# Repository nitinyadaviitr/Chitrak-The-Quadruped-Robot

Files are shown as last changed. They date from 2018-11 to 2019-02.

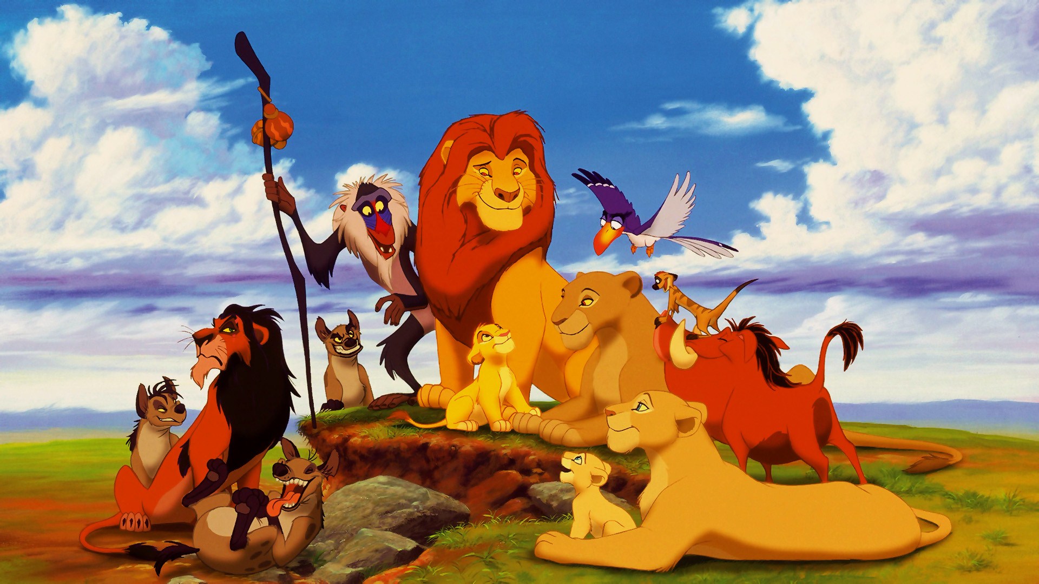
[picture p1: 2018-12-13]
PPT/The-Lion-King-complete-guide-to-the-lion-king-30912711-1920-1080.jpg

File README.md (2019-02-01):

MaRS_Kitty
Walking Quadruped Robot Kitty is a Quadruped that we are building under Models and Robotics Section, IIT Roorkee. 
This four legged walking robot will mimic the gait cycle of a cat with a soul purpose of providing help in natural calamities where 
normal robots find it difficult to move. 
Thank You.

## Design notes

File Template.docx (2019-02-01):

# KITTY ROBOT

Models and Robotics Section, Student Technical Council, IIT Roorkee

Replace this image. | Replace this image.

## About

Introduction

Less than half the Earth's landmass is accessible to existing wheeled and tracked vehicles. Our mission is to develop a rough-terrain robot that captures the mobility, autonomy, and speed of living creatures. Kitty will travel in outdoor terrain that is too steep, rutted, rocky, wet, muddy, and snowy land which clutter limit the utility of wheeled vehicles. Kitty Robot is aimed to be a dynamically stable quadruped robot with sophisticated computing, and power systems, advanced actuators and dynamic controls. For Short missions, the whole gear weighs nearly 58 Kg.

Weight decreases the amount of food and ammunition that can be carried in a single deployment, so supplies are to be provided to them again. Providing Backup Supplies and Care packages to soldiers increases the risk of life for Backup team. Kitty uses 4Lipo batteries(1 for each leg) which drives 8 Worm-Gear motors. Each leg has 2DOF. Each actuator unit consists of a rotary encoder attached to it for the feedback of angular rotation of leg about a joint.

Our Proposal

Utilize the space here for preliminary information about the project, motivation, execution, composition etc.

Team Size: 8

Impact on Society:

Ongoing Work

Problems With Current Robotic Waiters

How are we different from others?

Team Composition

Nitin Yadav

Yawan Gupta

Harshil Kumar Patel

Ujjwal Baranwal

Divyansh Gupta

Prashant Kumar

Avdesh Ranwa

Yashutosh Bansal

Replace this image. | Replace this image.

## Impact

Include key achievements, publications awards etc.

Highlight key learnings developed through the project etc.

## Contact

Models and Robotics Section

IIT Roorkee

Mail ID: nyadav@ee.iitr.ac.in

Website: mars.iitr.ac.in

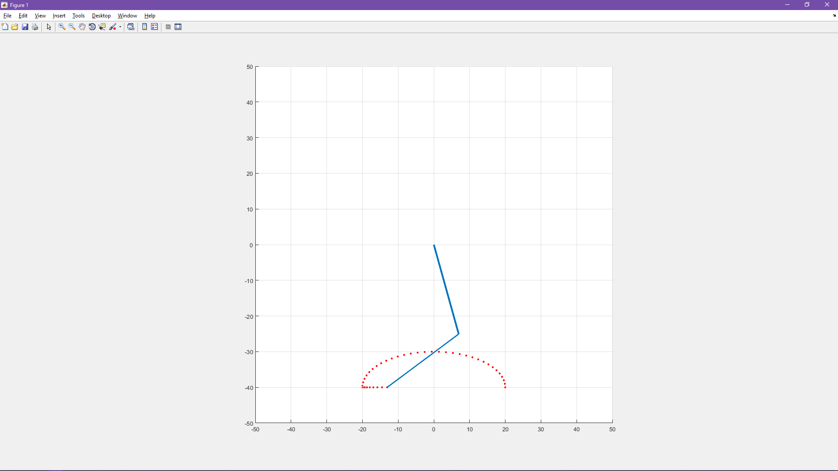
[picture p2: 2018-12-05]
PPT/Pics/Screenshot (137).png

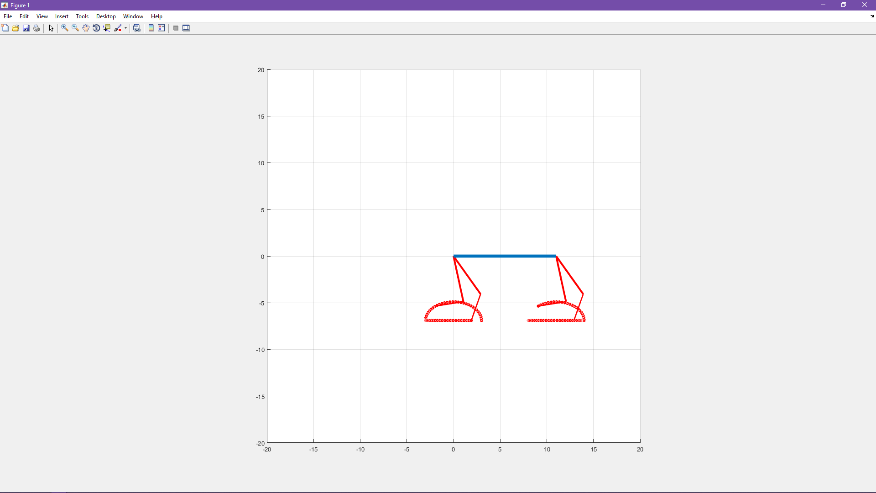
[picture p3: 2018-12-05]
PPT/Pics/Screenshot (147).png

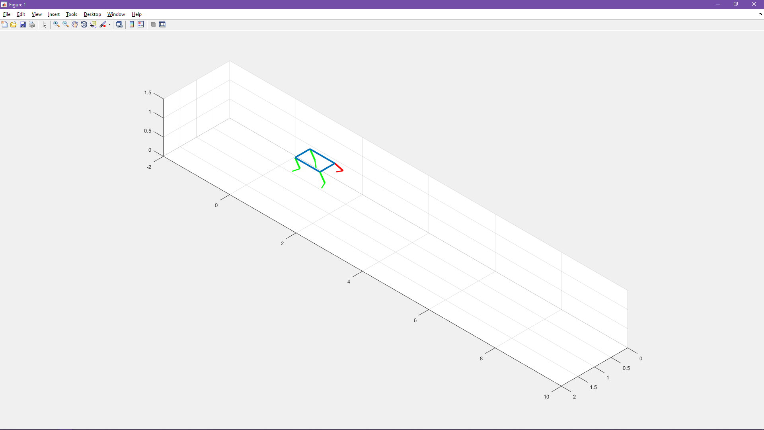
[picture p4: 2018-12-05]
PPT/Pics/Screenshot (134).png

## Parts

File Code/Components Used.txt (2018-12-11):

1. Cytron Motor Driver 4
2. LiPo Batteries 5
3. Rotary Encoders 8
4. Worm-Gear Motors 8
5. Arduino-Mega2560 2
6. MPU-9250 1

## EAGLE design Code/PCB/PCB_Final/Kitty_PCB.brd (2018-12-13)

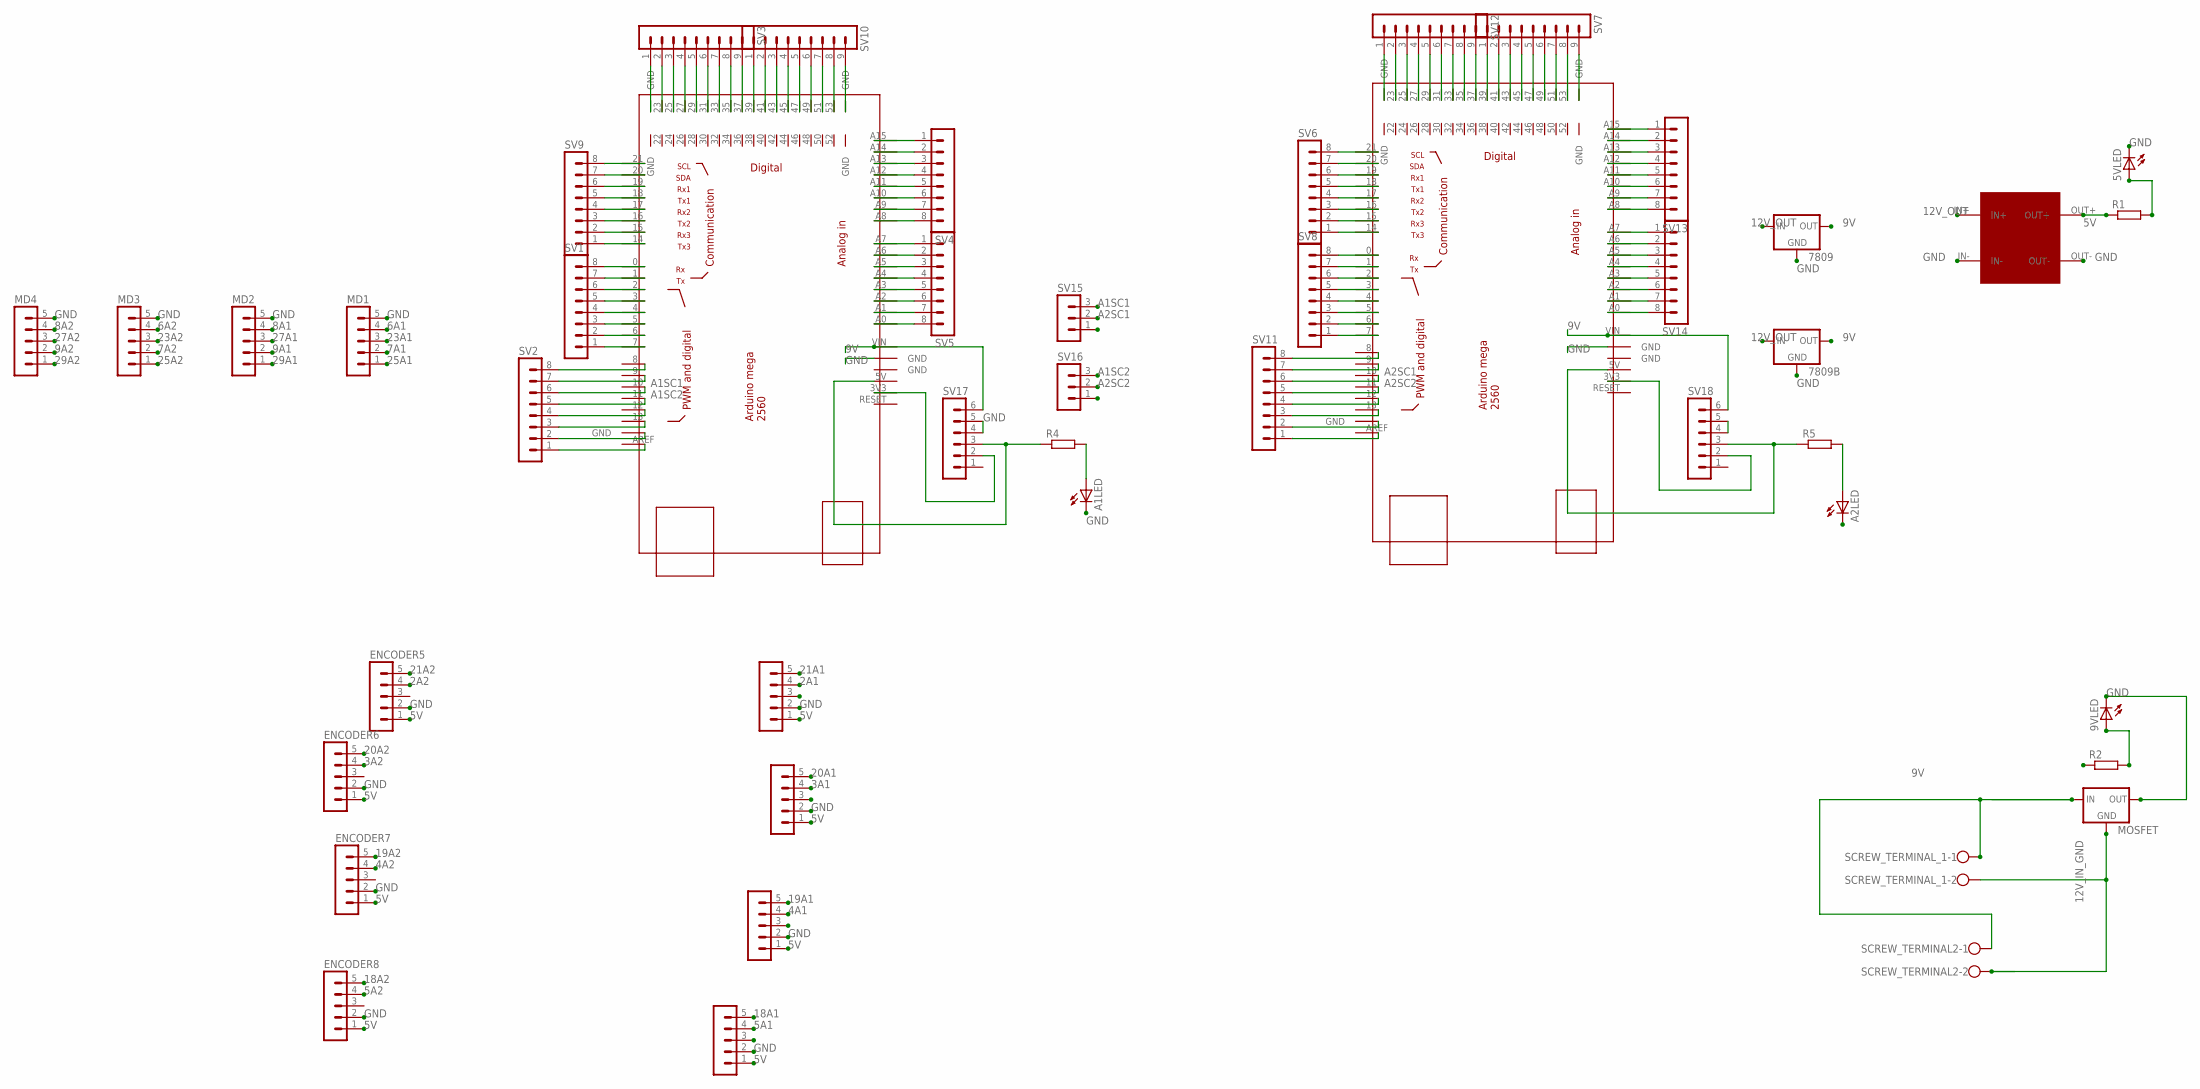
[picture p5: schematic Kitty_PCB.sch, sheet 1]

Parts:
5VLED, 9VLED: LED; LED3MM
7809, 7809B: VOLTAGE_REGULATOR_78XXS; 78XXS
A1LED, A2LED: LED; LED3MM
ARDUINO1, ARDUINO2: MEGA_DEVICE; MEGABOX
ENCODER1, ENCODER2, ENCODER3, ENCODER4, ENCODER5, ENCODER6, ENCODER7, ENCODER8: RELIMATE_05-1; MA05-1
MD1, MD2, MD3, MD4: RELIMATE_05-1; MA05-1
MOSFET: VOLTAGE_REGULATOR_78XXS; 78XXS
R1, R2, R4, R5: RESISTANCE0207/10; 0207/10
SCREW_TERMINAL2: SCREW_TERMINAL_POWER; POWER_CONNECTOR
SCREW_TERMINAL_1: SCREW_TERMINAL_POWER; POWER_CONNECTOR
SV1, SV2, SV4, SV5, SV6, SV8, SV9, SV11, SV13, SV14: RELIMATE_08-1; MA08-1
SV3, SV7, SV10, SV12: RELIMATE_09-1; MA09-1
SV15, SV16: RELIMATE_03-1; MA03-1
SV17, SV18: RELIMATE_06-1; MA06-1
U$1: BUCK_CONVERTER

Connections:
0A1: ARDUINO1.0, SV1.8
0A2: ARDUINO2.0, SV8.8
1A1: ARDUINO1.1, SV1.7
1A2: ARDUINO2.1, SV8.7
2A1: ARDUINO1.2, ENCODER1.4, SV1.6
2A2: ARDUINO2.2, ENCODER5.4, SV8.6
3A1: ARDUINO1.3, ENCODER2.4, SV1.5
3A2: ARDUINO2.3, ENCODER6.4, SV8.5
4A1: ARDUINO1.4, ENCODER3.4, SV1.4
4A2: ARDUINO2.4, ENCODER7.4, SV8.4
5A1: ARDUINO1.5, ENCODER4.4, SV1.3
5A2: ARDUINO2.5, ENCODER8.4, SV8.3
5V: ENCODER1.1, ENCODER2.1, ENCODER3.1, ENCODER4.1, ENCODER5.1, ENCODER6.1, ENCODER7.1, ENCODER8.1, R1.1, U$1.OUT+
6A1: ARDUINO1.6, MD1.4, SV1.2
6A2: ARDUINO2.6, MD3.4, SV8.2
7A1: ARDUINO1.7, MD1.2, SV1.1
7A2: ARDUINO2.7, MD3.2, SV8.1
8A1: ARDUINO1.8, MD2.4, SV2.8
8A2: ARDUINO2.8, MD4.4, SV11.8
9A1: MD2.2
9A2: ARDUINO1.9, ARDUINO2.9, MD4.2, SV2.7, SV11.7
9V: 7809.OUT, 7809B.OUT, ARDUINO1.VIN, ARDUINO2.VIN, R2.1, SV17.6, SV18.6
12A1: ARDUINO1.12, SV2.4
12A2: ARDUINO2.12, SV11.4
12V_IN_GND: MOSFET.GND, SCREW_TERMINAL2.2, SCREW_TERMINAL_1.2
12V_OUT: 7809.IN, 7809B.IN, MOSFET.IN, SCREW_TERMINAL2.1, SCREW_TERMINAL_1.1, U$1.IN+
13A1: ARDUINO1.13, SV2.3
13A2: ARDUINO2.13, SV11.3
14A1: ARDUINO1.14, SV9.1
14A2: ARDUINO2.14, SV6.1
15A1: ARDUINO1.15, SV9.2
15A2: ARDUINO2.15, SV6.2
16A1: ARDUINO1.16, SV9.3
16A2: ARDUINO2.16, SV6.3
17A1: ARDUINO1.17, SV9.4
17A2: ARDUINO2.17, SV6.4
18A1: ARDUINO1.18, ENCODER4.5, SV9.5
18A2: ARDUINO2.18, ENCODER8.5, SV6.5
19A1: ARDUINO1.19, ENCODER3.5, SV9.6
19A2: ARDUINO2.19, ENCODER7.5, SV6.6
20A1: ARDUINO1.20, ENCODER2.5, SV9.7
20A2: ARDUINO2.20, ENCODER6.5, SV6.7
21A1: ARDUINO1.21, ENCODER1.5, SV9.8
21A2: ARDUINO2.21, ENCODER5.5, SV6.8
23A1: ARDUINO1.23, MD1.3, SV3.2
23A2: ARDUINO2.23, MD3.3, SV12.2
25A1: ARDUINO1.25, MD1.1, SV3.3
25A2: ARDUINO2.25, MD3.1, SV12.3
27A1: ARDUINO1.27, MD2.3, SV3.4
27A2: ARDUINO2.27, MD4.3, SV12.4
29A1: ARDUINO1.29, MD2.1, SV3.5
29A2: ARDUINO2.29, MD4.1, SV12.5
31A1: ARDUINO1.31, SV3.6
31A2: ARDUINO2.31, SV12.6
33A1: ARDUINO1.33, SV3.7
33A2: ARDUINO2.33, SV12.7
35A1: ARDUINO1.35, SV3.8
35A2: ARDUINO2.35, SV12.8
37A1: ARDUINO1.37, SV3.9
37A2: ARDUINO2.37, SV12.9
A1SC1: ARDUINO1.10, SV2.6, SV15.3
A1SC2: ARDUINO1.11, SV2.5, SV16.3
A2SC1: ARDUINO2.10, SV11.6, SV15.2
A2SC2: ARDUINO2.11, SV11.5, SV16.2
GND: 5VLED.K (C), 9VLED.K (C), 7809.GND, 7809B.GND, A1LED.K (C), A2LED.K (C), ARDUINO1.GND@3 (GND), ARDUINO2.GND@3 (GND), ENCODER1.2, ENCODER2.2, ENCODER3.2, ENCODER4.2, ENCODER5.2, ENCODER6.2, ENCODER7.2, ENCODER8.2, MD1.5, MD2.5, MD3.5, MD4.5, MOSFET.OUT, SV17.4, SV17.5, U$1.IN-, U$1.OUT-
unnamed: ARDUINO1.3V3, SV17.2
unnamed: ARDUINO1.5V, R4.1, SV17.3
unnamed: 5VLED.A, R1.2
unnamed: SV18.4, SV18.5
unnamed: ARDUINO2.3V3, SV18.2
unnamed: ARDUINO2.5V, R5.1, SV18.3
unnamed: A1LED.A, R4.2
unnamed: A2LED.A, R5.2
unnamed: 9VLED.A, R2.2
unnamed: ARDUINO1.GND@5 (GND), SV3.1
unnamed: ARDUINO1.GND@1 (GND), SV2.2
unnamed: ARDUINO1.AREF, SV2.1
unnamed: ARDUINO1.A15, SV4.1
unnamed: ARDUINO1.A14, SV4.2
unnamed: ARDUINO1.A13, SV4.3
unnamed: ARDUINO1.A12, SV4.4
unnamed: ARDUINO1.A11, SV4.5
unnamed: ARDUINO1.A10, SV4.6
unnamed: ARDUINO1.A9, SV4.7
unnamed: ARDUINO1.A8, SV4.8
unnamed: ARDUINO1.A7, SV5.1
unnamed: ARDUINO1.A6, SV5.2
unnamed: ARDUINO1.A5, SV5.3
unnamed: ARDUINO1.A4, SV5.4
unnamed: ARDUINO1.A3, SV5.5
unnamed: ARDUINO1.A2, SV5.6
unnamed: ARDUINO1.A1, SV5.7
unnamed: ARDUINO1.A0, SV5.8
unnamed: ARDUINO2.GND@1 (GND), SV11.2
unnamed: ARDUINO2.AREF, SV11.1
unnamed: ARDUINO2.A15, SV13.1
unnamed: ARDUINO2.A14, SV13.2
unnamed: ARDUINO2.A13, SV13.3
unnamed: ARDUINO2.A12, SV13.4
unnamed: ARDUINO2.A11, SV13.5
unnamed: ARDUINO2.A10, SV13.6
unnamed: ARDUINO2.A9, SV13.7
unnamed: ARDUINO2.A8, SV13.8
unnamed: ARDUINO2.A7, SV14.1
unnamed: ARDUINO2.A6, SV14.2
unnamed: ARDUINO2.A5, SV14.3
unnamed: ARDUINO2.A4, SV14.4
unnamed: ARDUINO2.A3, SV14.5
unnamed: ARDUINO2.A2, SV14.6
unnamed: ARDUINO2.A1, SV14.7
unnamed: ARDUINO2.A0, SV14.8
unnamed: ARDUINO1.39, SV10.1
unnamed: ARDUINO1.41, SV10.2
unnamed: ARDUINO1.43, SV10.3
unnamed: ARDUINO1.45, SV10.4
unnamed: ARDUINO1.47, SV10.5
unnamed: ARDUINO1.49, SV10.6
unnamed: ARDUINO1.51, SV10.7
unnamed: ARDUINO1.53, SV10.8
unnamed: ARDUINO1.GND@7 (GND), SV10.9
unnamed: ARDUINO2.GND@5 (GND), SV12.1
unnamed: ARDUINO2.39, SV7.1
unnamed: ARDUINO2.41, SV7.2
unnamed: ARDUINO2.43, SV7.3
unnamed: ARDUINO2.45, SV7.4
unnamed: ARDUINO2.47, SV7.5
unnamed: ARDUINO2.49, SV7.6
unnamed: ARDUINO2.51, SV7.7
unnamed: ARDUINO2.53, SV7.8
unnamed: ARDUINO2.GND@7 (GND), SV7.9

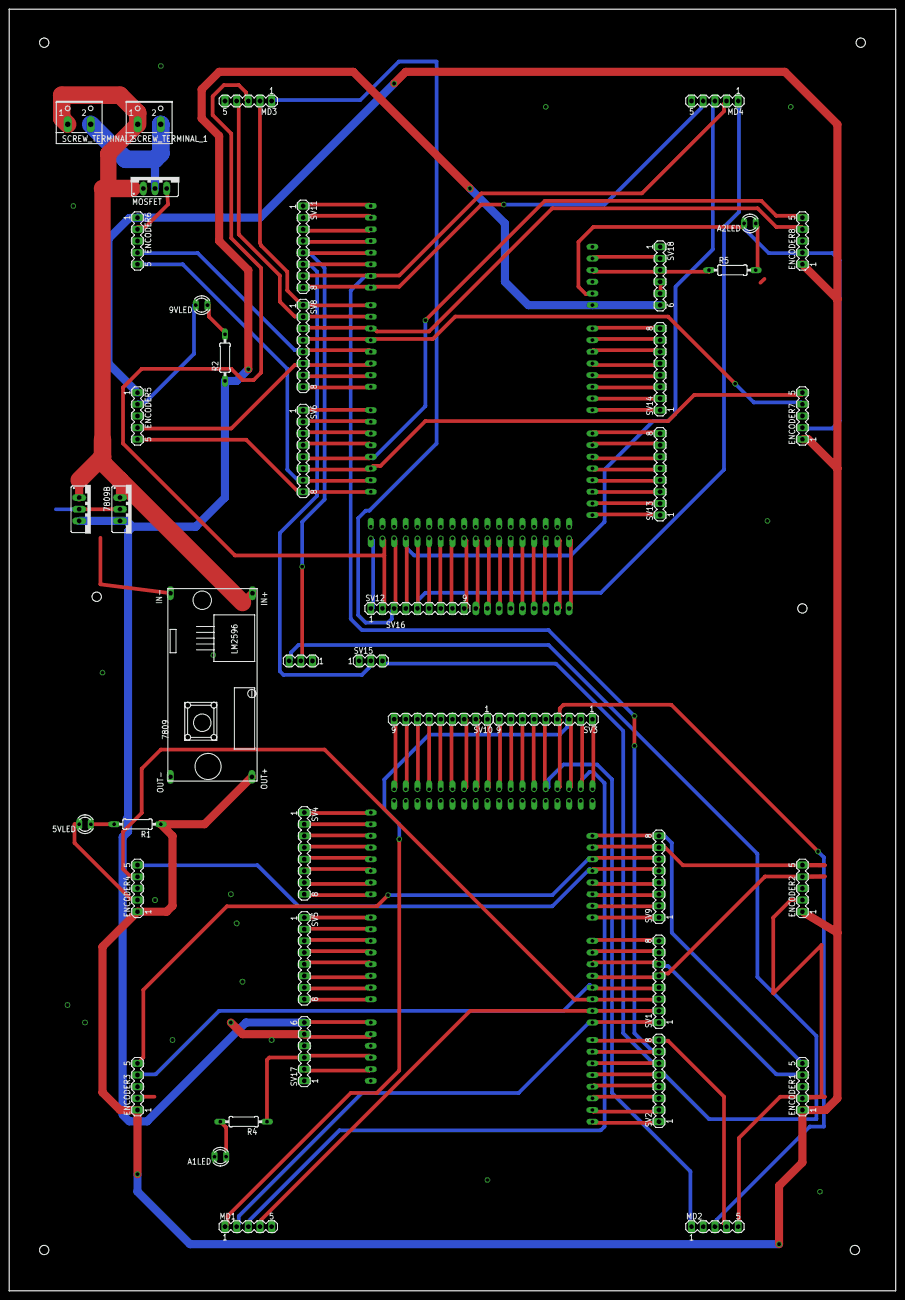
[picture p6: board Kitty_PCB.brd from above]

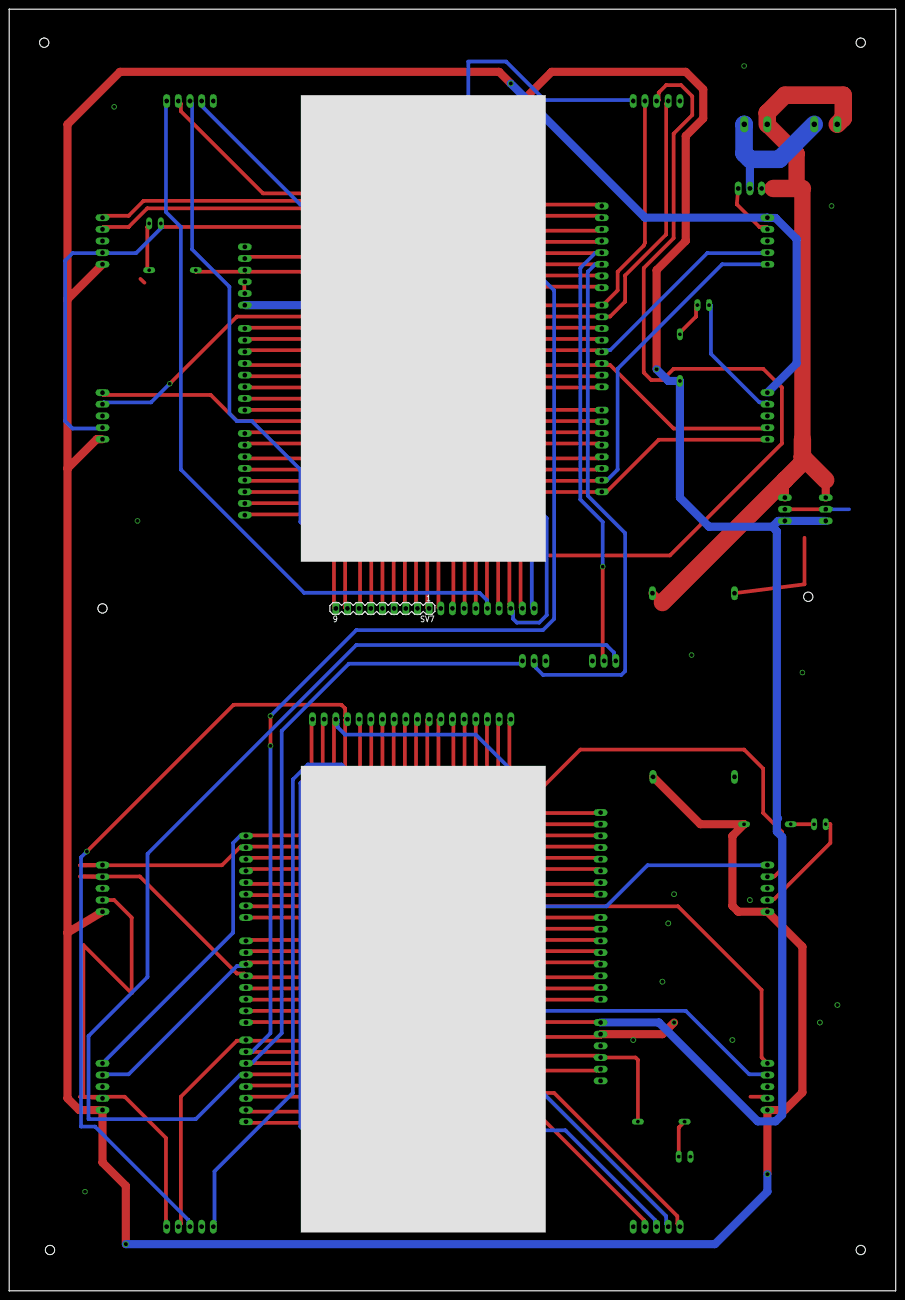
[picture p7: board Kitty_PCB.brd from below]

Board: 2 copper layers, 193.0 x 279.1 mm, 46 parts (3 on the bottom side), 129 nets.

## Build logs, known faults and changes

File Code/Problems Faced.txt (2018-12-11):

1. We are using 2 Arduino-Mega2560 so we need to use 1 attach_interrupt() pins instead of two for each encoder as Arduino Mega has 6 attach interrupts so we need atleast 2 Arduino to use 8 encoders.
2. In arduino mega, when we were using Tx-Rx pins(14-19) for writing analog value and direction into the motor driver, code was uploading but on giving the command to move the leg, no movement was observed. So we used digital pins(22-)for direction and only the PWM pins for writing the analog value, it worked properly.
3. For attach interrupt, we were using digitaltointerrupt() command for using interrupts and it did not work in mega but worked in uno. So we inserted manually the iterrupt pin number in Arduino-Mega from arduino website and it started working.
4. Encoder PPM value will be different to calculate angle when you are using one interrupt pin instead of two.
5. For applying Spline, the inverse Jacobian equation was to complex to be written in Arduino IDE, so we used a library for calculating inverse Matrix and perform other Matrix operations.
6. Timing Belt that was being used to hold the knee joint, was breaking very often. So we are searching for other alternatives.

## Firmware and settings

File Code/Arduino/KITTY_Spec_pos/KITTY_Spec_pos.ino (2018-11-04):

//Here 1 is for hip joint and 2 is for knee joint//
#define motor1  6
#define motor2  4
#define motor1pwm  10
#define motor2pwm  11

//Varaibles
float w=0.1, alpha, theta1c = 0.0 , theta2c = 0.0, theta1, theta2, error1, error2, correction1, correction2;
float dif_error1 , prev_error1 = 0.0 , dif_error2 , prev_error2 = 0.0 , I=0.0, l = 48.0;
float Kp1 = 0.75, Kp2 = 0.0, Kd1 = 0.3, Kd2 = 0.0 , Ki1 = 0.0;
int l1 = 26, l2 = 22, a = 20, b = 7;

//Encoder variables
volatile int temp1 , counter1 = 0;
volatile int temp2 , counter2 = 0;

void setup() {
  Serial.begin(9600);

  //Pins for encoders
  pinMode(2, INPUT_PULLUP);
  pinMode(3, INPUT_PULLUP);
  attachInterrupt(0, ai0, RISING);
  attachInterrupt(1, ai1, RISING);
  pinMode(20, INPUT_PULLUP);
  pinMode(21, INPUT_PULLUP);
  attachInterrupt(2, ai2, RISING);
  attachInterrupt(3, ai3, RISING);

  //Pins for Motors
  pinMode(motor1, OUTPUT);
  pinMode(motor1pwm, OUTPUT);
  pinMode(motor2, OUTPUT);
  pinMode(motor2pwm, OUTPUT);

  //Initial Conditions
//  digitalWrite(motor1, HIGH);
  
}
int flag =0;
void loop() {
if (flag == 1)
{ analogWrite(motor1pwm,0);
  Serial.println("stopped");
  }
  
 if (flag == 0){ 
  for (float t = 0; t <= 1000; t=t+0.3) {

    
//Ellipse coordinate update
//      float t = millis();
//      Serial.println(t);
//      float xe = a * cos(w*(t));
//      float ye = b * sin(w*(t)) - 40;
//      if (ye < -40) {
//    float  ye = -40;
//      }
    float xe = 48*cos(-35-w*(t) );
    float ye = 48*sin(-35-w*(t));

//Convert Encoder Output into angle
      if ( counter1 != temp1 ) {
        temp1 = counter1;
        if (counter1 > 1200) {
          counter1 = 0;
         }
        theta1c = - (counter1 * 0.3);
//        Serial.println (theta1c);
     }
      if ( counter2 != temp2 ) {
        temp2 = counter2;
        if (counter2 > 1200) {
          counter2 = 0;
        }
        theta2c = (counter2 * 0.3);
//        Serial.println (theta2c);
      }
//      

       

////Ellipse coordinates corresponding angle
      if (atan(ye / xe) > 0) {
        alpha = atan(ye / xe) - PI;
      }
      else {
        alpha = atan(ye / xe);
      }
      theta1 = 57.2958*(cosine_rule(l2, l1, sqrt((xe * xe) + (ye * ye))) + alpha);
      theta2 = 57.2958*(-PI + cosine_rule(sqrt(xe * xe + ye * ye), l1, l2));
      error1 = theta1 - theta1c;
      error2 = theta2 - theta2c;
      dif_error1 = error1 - prev_error1;
      prev_error1 = error1;
      dif_error2 = error2 - prev_error2;
      prev_error2 = error2;
      
      I += error1;
      correction1 = Kp1*error1 + Kd1*(dif_error1);//+ Ki1*(I);
      correction2 = Kp2*error2 + Kd2*(dif_error2);
//      Serial.println(error1);
//      correction1 = Kp1*error1;
//      correction2 = Kp2*error2;
      Serial.println(correction1);
//      Moving condtions
      if(theta1c < -30.0){
        flag = 1;
        break;
        }
      if(error1<0 ){
        upr_mtr_fwd();
        analogWrite(motor1pwm,abs(correction1));
        }
       else if(error1>0){
        upr_mtr_bwd();
        analogWrite(motor1pwm,abs(correction1));
        }

//      if(error2<0){
//        lwr_mtr_fwd();
//        analogWrite(motor2pwm,abs(correction2));
//        }
//      else if(error2>0){
//        lwr_mtr_bwd();
//        analogWrite(motor2pwm,abs(correction2));
//        }
//
////   float t0 = millis();
////   Serial.println(t0-t);
  }
 }
}

//Cosine Rule
float cosine_rule(float c, float b, float a) {
  float x = ( a * a + b * b - c * c ) / ( 2 * a * b );
  return acos(x);
}

//motor directions
void upr_mtr_fwd() {
  digitalWrite(motor1, HIGH);
}

void upr_mtr_bwd() {
  digitalWrite(motor1, LOW);
}

void lwr_mtr_fwd() {
  digitalWrite(motor2, HIGH);
}

void lwr_mtr_bwd() {
  digitalWrite(motor2, LOW);
}

//Encoder1
void ai0() {
  if (digitalRead(3) == LOW) {
    counter1++;
  } else {
    counter1--;
  }
}

void ai1() {
  if (digitalRead(2) == LOW) {
    counter1--;
  } else {
    counter1++;
  }
}

//  Encoder2
void ai2() {
  if (digitalRead(20) == LOW) {
    counter2++;
  } else {
    counter2--;
  }
}

void ai3() {
  if (digitalRead(21) == LOW) {
    counter2--;
  } else {
    counter2++;
  }
}

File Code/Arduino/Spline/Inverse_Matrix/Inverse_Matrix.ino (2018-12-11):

#include <MatrixMath.h>

#define N  (3)

mtx_type A[N][N];

mtx_type maxVal = 10;  // maxValimum random matrix entry range

void setup()
{
  Serial.begin(9600);

  // Initialize matrices
  for (int i = 0; i < N; i++)
  {          
    for (int j = 0; j < N; j++)
    {
      A[i][j] = random(maxVal) - maxVal / 2.0f; // A is random
    }
  }

}

void loop()
{
  Serial.println("\nA:");
  Matrix.Print((mtx_type*)A, N, N, "");
  Matrix.Invert((mtx_type*)A, N);
  Serial.println("\nInverted A:");
  Matrix.Print((mtx_type*)A, N, N, "A");

  while (1);
}

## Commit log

2018-11-04 Gait Correction
    Reduce the instant Jerk on 2 legs
2018-11-05 Code with communication
    Individual arduino code done, master left.
2018-12-05 Code for 4legs
    New changes made for smooth movement of four legs.
2018-12-07 PCB
    PCB design for the bot
    [Kitty_PCB.brd, Kitty_PCB.sch]
2018-12-10 PCB 1.0 Final
    1st version of the PCB is completed.
    [Kitty_PCB.brd, Kitty_PCB.sch]
2018-12-11 New Things To be Added
    Integrating IMU for COM position
    Storing value in EEPROM of Arduino for repositioning off the bot each time it starts.
    Adding Spline to the motion of 1leg.
    [Kitty_PCB.brd, Kitty_PCB.sch]
2018-12-13 PCB1 Final
    Final PCB for ettching completed.
    [Kitty_PCB.brd, Kitty_PCB.sch]
